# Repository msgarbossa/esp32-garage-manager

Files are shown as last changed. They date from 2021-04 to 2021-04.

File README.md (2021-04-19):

# ESP32 Garage Manager

## Basic features

- Remotely trigger a relay to open the garage door
- Magentic reed switch is used to determine whether the garage door is open or closed and send events when the state changes
- AHT10 temperature and humidity sensor sends regular updates (BME280 can be used instead using functions/temp-bme280.h instead of temp-ah10.h)
- Water leak sensor via a capacitive touch pin, intended to monitor a hot water heater for leaks
- OLED display alternates between Temp/Humidity and basic information (IP, device name, WiFi connection state, WiFi signal strength, door state, leak state)
- MQTT is used to publish and subscribe messages
- Node-RED interface to MQTT to process data, export Prometheus metrics, and send alerts for leaks or door left open at night
- Home Assistant and phone app is used for dashboard button to trigger door

## Parts

- [ESP32 devkit - 30 pin, integrated antenna](https://www.aliexpress.com/item/1005001267643044.html)
- [0.96" OLED - white, I2C](https://www.aliexpress.com/item/32896971385.html)
- [BME280 sensor](https://www.aliexpress.com/item/4001098967210.html) or [AHT10 sensor](https://www.aliexpress.com/item/4000125110813.html)
- [relay](https://www.aliexpress.com/item/32908761529.html)
- [magnetic reed switch](https://www.aliexpress.com/item/4001283716814.html)
- [passive piezo buzzer](https://www.aliexpress.com/item/4001317667682.html) or anything to make noise
- [alarm wire](https://www.amazon.com/gp/product/B01CT06M0A/) (500') - Used for magnetic reed switch connection, but useful for other connections.  It's 22 awg solid wire, which is easier to work with and solder than some of the cheap stranded wire.

## Diagram

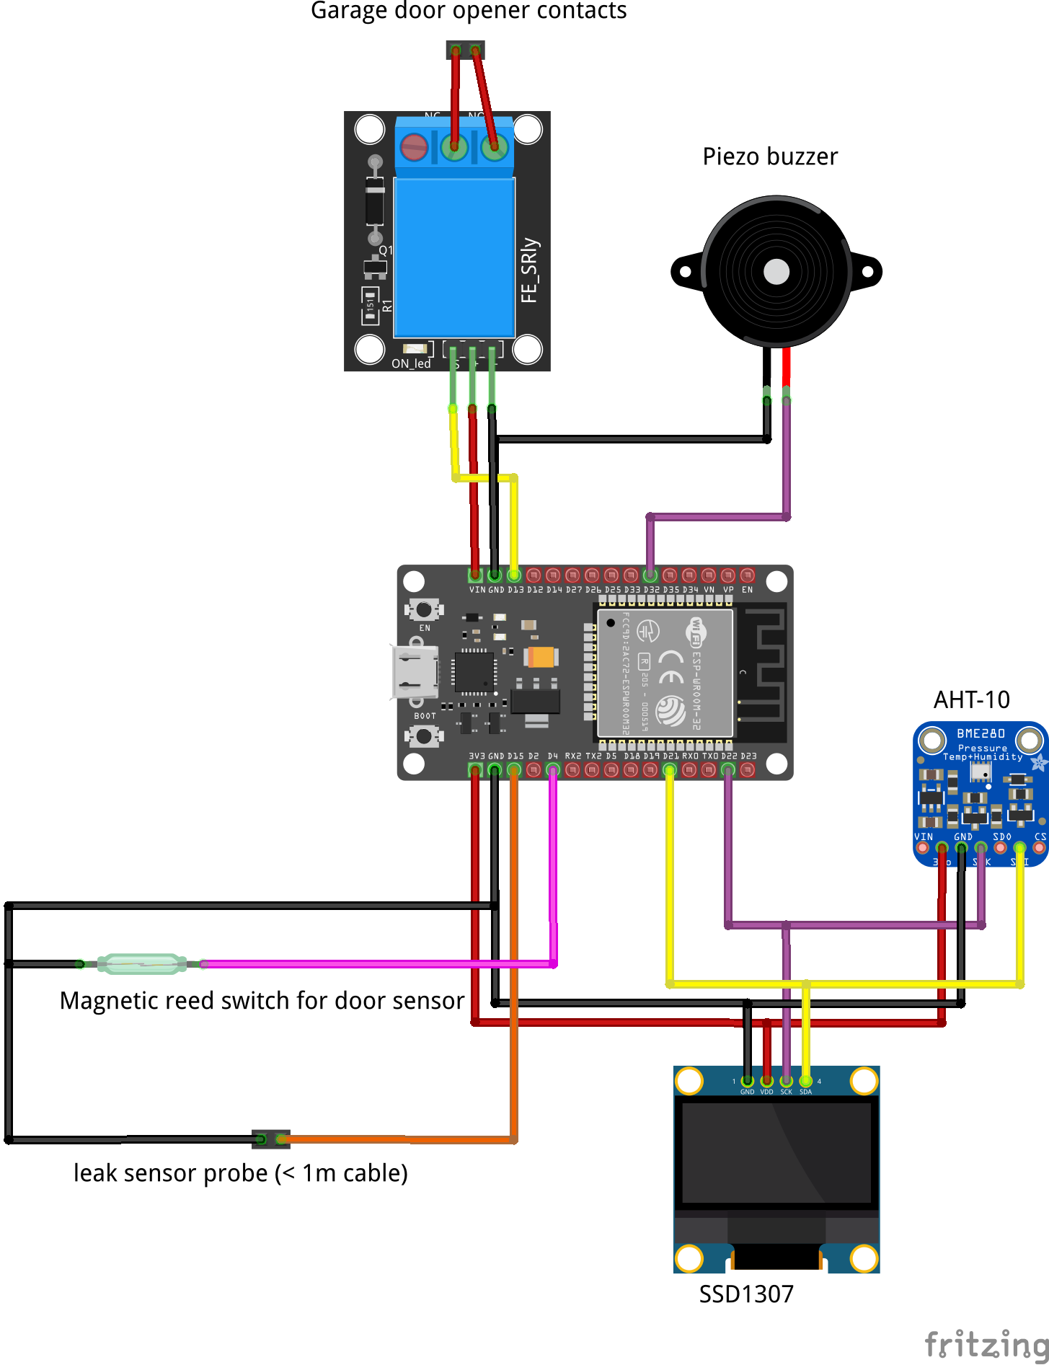
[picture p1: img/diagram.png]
diagram


## Assembly

I use these [inexepensive cases (10-pack)](https://www.amazon.com/gp/product/B07HKWNB93/), which are pretty easy for prototyping.  They can be cut with an X-acto knife and the X-acto knife can also "drill" holes with the tip. 

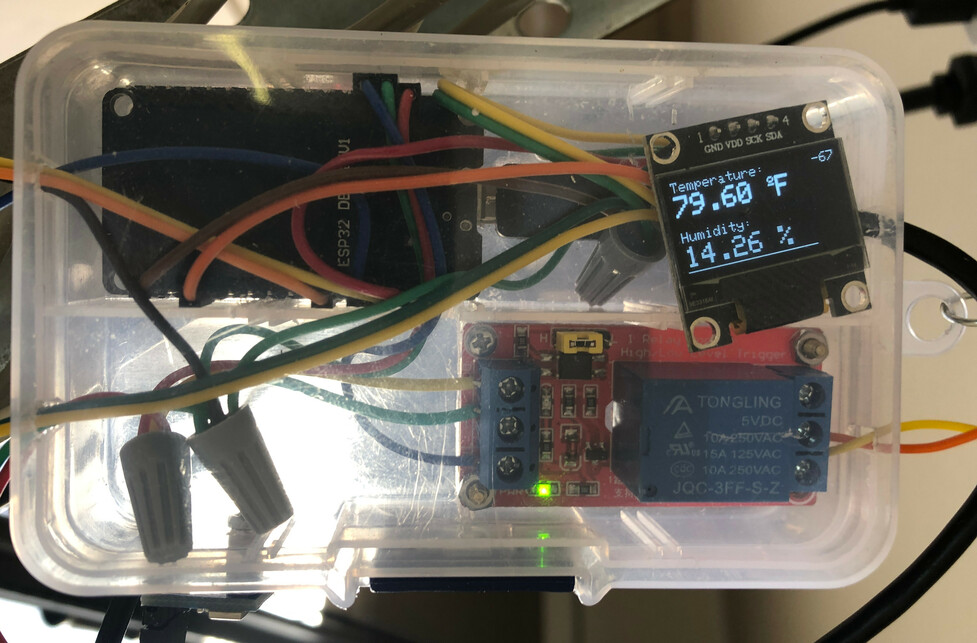
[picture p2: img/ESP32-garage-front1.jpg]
front1


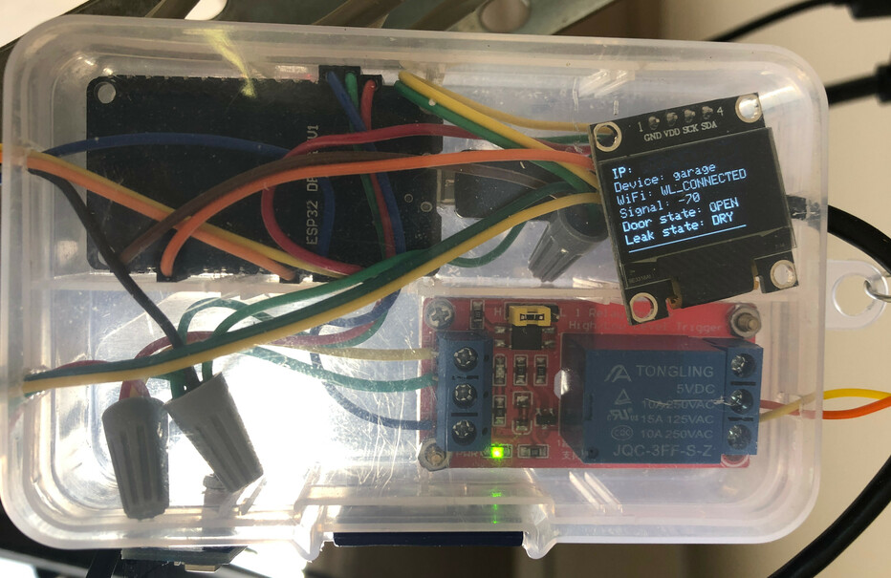
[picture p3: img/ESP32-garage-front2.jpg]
front2


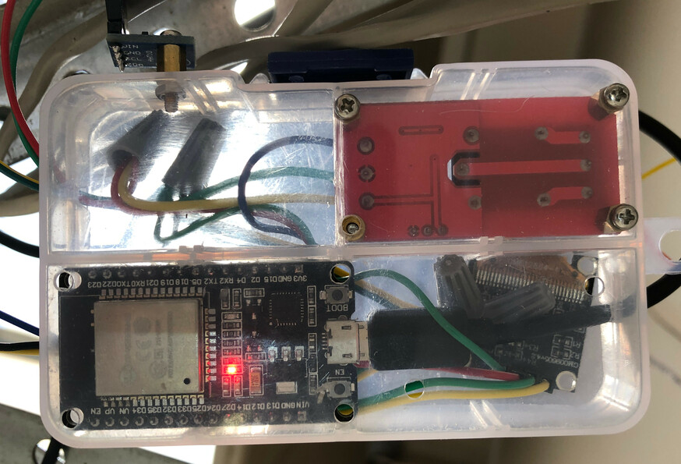
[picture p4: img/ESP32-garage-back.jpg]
back


The alarm wire can be used to run longer connections to the magnetic door sensor switch and the contacts for triggering the garage door.  If using the leak sensor, the ESP32 will need to be located near the leak sensor (\< 1 meter).  Dental-floss cases worked well due to the clamshell design and soft plastic.

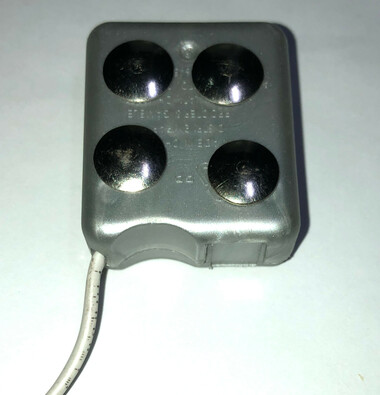
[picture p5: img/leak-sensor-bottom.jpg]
leak-sensor-bottom
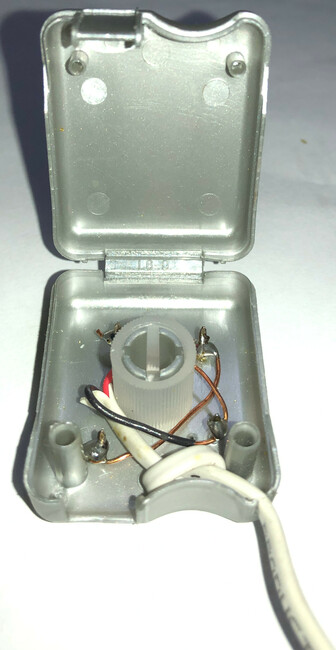
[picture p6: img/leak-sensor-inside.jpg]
leak-sensor-inside
  

## Node-RED

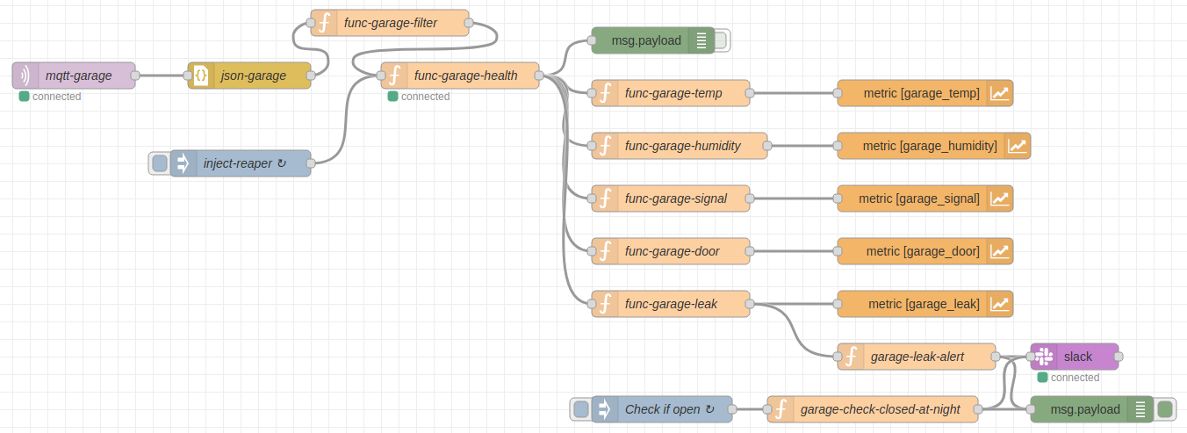
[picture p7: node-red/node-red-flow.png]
Node-RED flow

[JSON for above flow](node-red/flow.json)

The beginnig of the flow starts out very simple.  Node-RED listens on the MQTT topic for the sensor.  The messages get converted from JSON to payload objects.

To understand the rest of the flow, it's important to go over how the Prometheus node exporter works in Node-RED.  The orange metric boxes to the right-side of the flow generate the prometheus data shown below at \<node_red_url\>:1880/metrics.

```
# HELP garage_temp garage temp
# TYPE garage_temp gauge
garage1_temp 83.1

# HELP garage_humidity garage humidity
# TYPE garage_humidity gauge
garage_humidity 22.58

# HELP garage_signal garage signal
# TYPE garage_signal gauge
garage_signal -61

# HELP garage_door garage door
# TYPE garage_door gauge
garage_door 0

# HELP garage_leak garage leak
# TYPE garage_leak gauge
garage_leak 0
```

The challenge has been dealing with sensors that go offline.  The metric node would not receive an updated value and continue to display an old value.  This would show up in the graphs in Grafana as a flat-line.  There might be a more elegant solution, but what I've done for now is to use an inject node to regularly inject a healthcheck message into the flow.  The healthcheck function node uses node context to store the time of the last valid message that came from MQTT.  When the healthcheck message is injected, the time of the inject message is compared to the time of the last valid message.  If the time difference is greater than the threshold, the healthcheck node's status is set to "offline" and a new message is generated and passed along with the metric values set to zero.  The Grafana graphs are set to only display values greater than zero.

The functions to the left of each of the orange metric nodes simply reformat the payload messages to set the metric values as required for the Promtheus metric nodes.

The "Check if open" inject node is scheduled to check if the garage door is open at night.  There are 2 alert processing functions that send messages to Slack (door open and leak events).

Below is an example graph in Grafana.

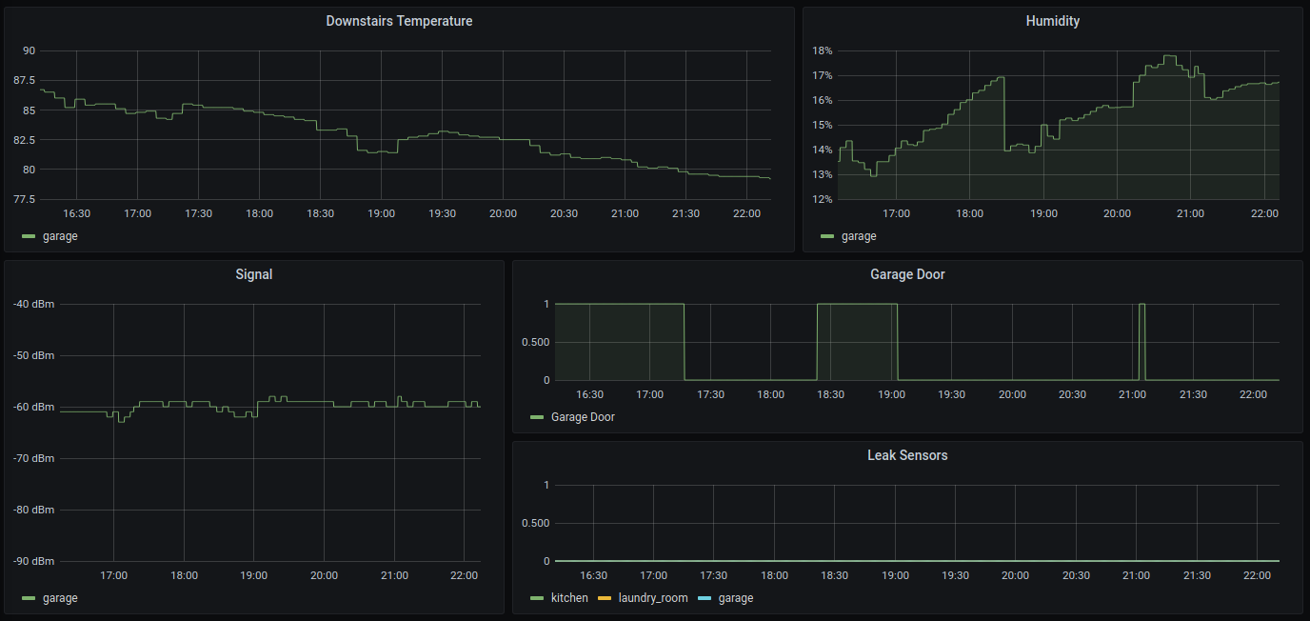
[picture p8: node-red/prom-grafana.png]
Prometheus - Grafana


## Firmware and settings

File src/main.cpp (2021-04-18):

#include <Arduino.h>
#include <WiFi.h>
extern "C" {
  #include "freertos/FreeRTOS.h"
  #include "freertos/timers.h"
}
#include <AsyncMqttClient.h>
#include <SPI.h>
#include <Wire.h>
#include <Adafruit_GFX.h>
#include <Adafruit_SSD1306.h>

#include "config/config.h"
#include "functions/ota.h"
#include "functions/attention.h"
#include "functions/temp-aht10.h"
#include "tasks/garage-door.h"
#include "tasks/leak-detect.h"

#ifdef __arm__
// should use uinstd.h to define sbrk but Due causes a conflict
extern "C" char* sbrk(int incr);
#else  // __ARM__
extern char *__brkval;
#endif  // __arm__

#define SCREEN_WIDTH 128 // OLED display width, in pixels
#define SCREEN_HEIGHT 64 // OLED display height, in pixels

// Declaration for an SSD1306 display connected to I2C (SDA, SCL pins)
#define OLED_RESET     -1 // Reset pin # (or -1 if sharing Arduino reset pin)
Adafruit_SSD1306 display(SCREEN_WIDTH, SCREEN_HEIGHT, &Wire, OLED_RESET);

// Variables to hold sensor readings
float temp;
float humidity;
// float pressure;
int doorStatus;
bool doorChanged;
int leakStatus;
bool leakChanged;

// Variables to hold sensor info
int8_t wifi_strength;
IPAddress ip;

unsigned short int displayCount = 2;

// Temperature MQTT Topics
#define MQTT_PUB_TEMP "home/" DEVICE_NAME "/metrics"
#define MQTT_SUB_CMD "home/" DEVICE_NAME "/cmd"

AsyncMqttClient mqttClient;
TimerHandle_t mqttReconnectTimer;
TimerHandle_t wifiReconnectTimer;
TimerHandle_t checkDoorTimer;
TimerHandle_t checkLeakTimer;

const long intervalMQTT   = 300000;    // Interval at which to publish sensor readings
unsigned long prevMillisMQTT = 0;   // Stores last time sensor was published
const long intervalSensor = 60000;    // Interval at which to read sensor and update display
unsigned long prevMillisSensor = 0;   // Stores last time sensor was published
unsigned long prevMillisDisplay = 0;   // Stores last time display was updated
const unsigned long intervalAlertMillis = 30000;  // How often to alert when leak sensor is wet
unsigned long prevMillisAlert = 0;
unsigned int countdownPerc;


const char* wl_status_to_string(int status) {
  switch (status) {
    case WL_NO_SHIELD: return "WL_NO_SHIELD";
    case WL_IDLE_STATUS: return "WL_IDLE_STATUS";
    case WL_NO_SSID_AVAIL: return "WL_NO_SSID_AVAIL";
    case WL_SCAN_COMPLETED: return "WL_SCAN_COMPLETED";
    case WL_CONNECTED: return "WL_CONNECTED";
    case WL_CONNECT_FAILED: return "WL_CONNECT_FAILED";
    case WL_CONNECTION_LOST: return "WL_CONNECTION_LOST";
    case WL_DISCONNECTED: return "WL_DISCONNECTED";
    default: return "UNKNOWN";
  }
}

void connectToWifi() {
  btStop(); // turn off bluetooth
  Serial.println("Connecting to Wi-Fi...");
  WiFi.begin(WIFI_NETWORK, WIFI_PASSWORD);
}

void connectToMqtt() {
  Serial.println("Connecting to MQTT...");
  mqttClient.connect();
}

void WiFiEvent(WiFiEvent_t event) {
  Serial.printf("[WiFi-event] event: %d\n", event);
  switch(event) {
    case SYSTEM_EVENT_STA_GOT_IP:
      Serial.println("WiFi connected");
      Serial.println("IP address: ");
      ip = WiFi.localIP();
      Serial.println(WiFi.localIP());
      connectToMqtt();
      break;
    case SYSTEM_EVENT_STA_DISCONNECTED:
      Serial.println("WiFi lost connection");
      xTimerStop(mqttReconnectTimer, 0); // ensure we don't reconnect to MQTT while reconnecting to Wi-Fi
      xTimerStart(wifiReconnectTimer, 0);
      break;
    default:
      break;
  }
}

void updateWiFiSignalStrength() {
  if(WiFi.isConnected()) {
    //serial_println(F("[WIFI] Updating signal strength..."));
    wifi_strength = WiFi.RSSI();
    // Serial.print("[WIFI] signal strength: ");
    // Serial.println(wifi_strength);
  }
}

void onMqttConnect(bool sessionPresent) {
  Serial.println("Connected to MQTT.");
  Serial.print("Session present: ");
  Serial.println(sessionPresent);
  uint16_t packetIdSub = mqttClient.subscribe(MQTT_SUB_CMD, 2);
  Serial.print("Subscribing at QoS 2, packetId: ");
  Serial.println(packetIdSub);
}

void onMqttDisconnect(AsyncMqttClientDisconnectReason reason) {
  Serial.println("Disconnected from MQTT.");
  if (WiFi.isConnected()) {
    xTimerStart(mqttReconnectTimer, 0);
  }
}

void onMqttPublish(uint16_t packetId) {
  Serial.print("Publish acknowledged.");
  Serial.print("  packetId: ");
  Serial.println(packetId);
}

void drawMeasurementProgress(int perc) {
  const byte Y = SCREEN_HEIGHT - 2;
  // display.drawRect(x, y, width, height, color)
  display.drawRect(0, Y, int(SCREEN_WIDTH * (perc/100.0)), 1, WHITE);
}

void displayStats() {
  // clear display
  display.clearDisplay();
  
  // display temperature
  display.setTextSize(1);
  display.setCursor(0,0);
  display.print("Temperature: ");
  display.setTextSize(2);
  display.setCursor(0,10);
  display.print(temp);
  display.print(" ");
  display.setTextSize(1);
  display.cp437(true);
  display.write(167);
  display.setTextSize(2);
  display.print("F");
  
  // display humidity
  display.setTextSize(1);
  display.setCursor(0, 35);
  display.print("Humidity: ");
  display.setTextSize(2);
  display.setCursor(0, 45);
  display.print(humidity);
  display.print(" %");

  // display wifi signal strength
  display.setTextSize(1);
  display.setCursor(110, 0);
  display.print(String(wifi_strength));

  drawMeasurementProgress(countdownPerc);
  
  display.display();
  //delay(1000); // Pause for 1 second
  vTaskDelay(1000 / portTICK_PERIOD_MS);
}

void displayInfo() {

  String currentState = wl_status_to_string(WiFi.status());

  // clear display
  display.clearDisplay();
  
  // display temperature
  display.setTextSize(1);
  display.setCursor(0,0);
  display.print("IP: ");
  display.print(ip);
  display.setCursor(0,10);
  display.print("Device: ");
  display.print(DEVICE_NAME);
  display.setCursor(0,20);
  display.print("WiFi: ");
  display.print(currentState);
  display.setCursor(0,30);
  display.print("Signal: ");
  display.print(String(wifi_strength));
  display.setCursor(0,40);
  display.print("Door state: ");
  if (doorStatus == 0) {
   display.print("CLOSED"); 
  } else {
    display.print("OPEN"); 
  }
  display.setCursor(0,50);
  display.print("Leak state: ");
  if (leakStatus == 0) {
   display.print("DRY"); 
  } else {
    display.print("WET"); 
  }

  drawMeasurementProgress(countdownPerc);

  display.display();
  vTaskDelay(1000 / portTICK_PERIOD_MS);
}

void sendMqttUpdate() {
  char msg[58];  // variable for MQTT payload
  sprintf(msg, "{\"t\":\"%0.2f\",\"h\":\"%0.2f\",\"s\":\"%d\",\"d\":\"%d\",\"w\":\"%d\"}", temp, humidity, wifi_strength, doorStatus, leakStatus);
  // uint16_t packetIdPub1 = mqttClient.publish(MQTT_PUB_TEMP, 1, true, msg);
  uint16_t packetIdPub1 = mqttClient.publish(MQTT_PUB_TEMP, 0, false, msg);
  Serial.printf("[MQTT] Publishing on topic %s at QoS 1, packetId: %i\n", MQTT_PUB_TEMP, packetIdPub1);
  Serial.println(msg);
}

void onMqttSubscribe(uint16_t packetId, uint8_t qos) {
  Serial.println("Subscribe acknowledged.");
  Serial.print("  packetId: ");
  Serial.println(packetId);
  Serial.print("  qos: ");
  Serial.println(qos);
}
void onMqttUnsubscribe(uint16_t packetId) {
  Serial.println("Unsubscribe acknowledged.");
  Serial.print("  packetId: ");
  Serial.println(packetId);
}

void onMqttMessage(char* topic, char* payload, AsyncMqttClientMessageProperties properties, size_t len, size_t index, size_t total) {
  Serial.println("Publish received.");
  Serial.print("  topic: ");
  Serial.println(topic);
  Serial.print("  qos: ");
  Serial.println(properties.qos);
  Serial.print("  dup: ");
  Serial.println(properties.dup);
  Serial.print("  retain: ");
  Serial.println(properties.retain);
  Serial.print("  len: ");
  Serial.println(len);
  Serial.print("  index: ");
  Serial.println(index);
  Serial.print("  total: ");
  Serial.println(total);

  char s_payload[len + 1];
  String payload2 = "";
  if (len < 20) {
    Serial.print("  payload: ");
    s_payload[len] = '\0';
    strncpy(s_payload, payload, len);
    Serial.println(s_payload);
    payload2 = s_payload;
  } else {
    Serial.println(" payload len>20");
  }
  if (payload2 == "blink") {
    blink_now();
    prevMillisMQTT = 0;
  }
  if (payload2 == "toggle") {
    play_sound();
    toggleGarageRelay();
  }

}

void setup() {
  Serial.begin(115200);
  Serial.println();
  pinMode (LED_PIN, OUTPUT);

  Wire.begin(I2C_SDA, I2C_SCL);

  // SSD1306_SWITCHCAPVCC = generate display voltage from 3.3V internally
  if(!display.begin(SSD1306_SWITCHCAPVCC, 0x3C)) { 
    Serial.println(F("SSD1306 allocation failed"));
    for(;;); // Don't proceed, loop forever
  }
  display.clearDisplay();
  display.setTextColor(WHITE);

  // Set up temp sensor
  setupTemp();

  // Set up garage dooor monitor and leak monitor
  monitorDoorSetup();
  leakSetup();
  
  mqttReconnectTimer = xTimerCreate("mqttTimer", pdMS_TO_TICKS(2000), pdFALSE, (void*)0, reinterpret_cast<TimerCallbackFunction_t>(connectToMqtt));
  wifiReconnectTimer = xTimerCreate("wifiTimer", pdMS_TO_TICKS(2000), pdFALSE, (void*)0, reinterpret_cast<TimerCallbackFunction_t>(connectToWifi));
  checkDoorTimer = xTimerCreate("doorTimer", pdMS_TO_TICKS(GARAGE_DOOR_MONITOR_MS), pdTRUE, (void*)0, reinterpret_cast<TimerCallbackFunction_t>(monitorDoorState));
  checkLeakTimer = xTimerCreate("leakTimer", pdMS_TO_TICKS(LEAK_MONITOR_MS), pdTRUE, (void*)0, reinterpret_cast<TimerCallbackFunction_t>(checkLeakStatus));

  WiFi.onEvent(WiFiEvent);

  mqttClient.onConnect(onMqttConnect);
  mqttClient.onDisconnect(onMqttDisconnect);
  mqttClient.onSubscribe(onMqttSubscribe);
  mqttClient.onUnsubscribe(onMqttUnsubscribe);
  mqttClient.onMessage(onMqttMessage);
  mqttClient.onPublish(onMqttPublish);
  mqttClient.setServer(MQTT_HOST, MQTT_PORT);
  mqttClient.setCredentials(MQTT_USER, MQTT_PASSWORD);
  connectToWifi();
  setupOTA();
  xTimerStart(checkDoorTimer, 0);
  xTimerStart(checkLeakTimer, 0);
}

void loop() {
  ArduinoOTA.handle();

  unsigned long currentMillis = millis();
  bool forceMqttUpdate = false;

  // read sensor every intervalSensor millis
  if (currentMillis - prevMillisSensor >= intervalSensor) {
    // Save the last time a new reading was published
    prevMillisSensor = currentMillis;
    measureTemp();
  }

  // update display every DISPLAY_INTERVAL and rotate display screens
  if (currentMillis - prevMillisDisplay >= DISPLAY_INTERVAL) {
    prevMillisDisplay = currentMillis;
    countdownPerc = 100-(((currentMillis-prevMillisMQTT)/double(intervalMQTT))*100);  // time until MQTT interval expires
    updateWiFiSignalStrength();
    if (displayCount == 2) {
      displayStats();
      displayCount = 1;
    } else {
      displayInfo();
      displayCount = 2;
    }
  }

  if ((doorChanged == true) || (leakChanged == true)) {
    forceMqttUpdate = true;
  }

  // If wet, do sound alert every intervalAlertMillis
  if (leakStatus == 1) {
    if (currentMillis - prevMillisAlert >= intervalAlertMillis) {
      prevMillisAlert = millis();
      blink_now();
    }
  }

  // publish a new MQTT message everyintervalMQTT millis
  if ((currentMillis - prevMillisMQTT >= intervalMQTT) || (forceMqttUpdate == true)) {
    // Save the last time a new reading was published
    prevMillisMQTT = currentMillis;
    doorChanged = false;
    leakChanged = false;
    blink_now();
    sendMqttUpdate();
  }
}

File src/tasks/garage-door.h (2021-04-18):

// #define CLOSED LOW	
// #define OPEN HIGH

#include <Arduino.h>
#include "../config/config.h"

extern bool doorChanged;
extern int doorStatus;

short int getDoorStatus() {
    // digitalRead returns 1/HIGH/OPEN or 0/LOW/CLOSED
    // LOW = magnetic switch connected = door closed
    // HIGH = magentic switch broken = door open
    short int status = digitalRead(GARAGE_MAG_SWITCH_PIN);
    return status;
}

void monitorDoorSetup() {
    // pinMode(GARAGE_RELAY_PIN, INPUT_PULLUP);  // for the odd relay triggered by grounding the input pin
    pinMode(GARAGE_RELAY_PIN, OUTPUT);  // for stardard relay (triggered w/ 3.3V)
    pinMode(GARAGE_MAG_SWITCH_PIN, INPUT_PULLUP);
    doorStatus = getDoorStatus();
}

void toggleGarageRelay() {
    Serial.println("Garage relay toggle");
    // pinMode(GARAGE_RELAY_PIN, OUTPUT);  // for the odd relay triggered by grounding the input pin
    digitalWrite(GARAGE_RELAY_PIN, HIGH); // turn on the relay (standard relay triggered w/ 3.3V)
    vTaskDelay(300 / portTICK_PERIOD_MS);
    // pinMode(GARAGE_RELAY_PIN, INPUT_PULLUP);  // for the odd relay triggered by grounding the input pin
    digitalWrite(GARAGE_RELAY_PIN, LOW);  // turn off the relay (standard relay triggered w/ 3.3V)
}

void monitorDoorState() {
    short int newDoorStatus = getDoorStatus();
    if (newDoorStatus != doorStatus) {
        doorStatus = newDoorStatus;
        doorChanged = true;
        Serial.print("[GARAGE] Door has changed to: ");
        if (doorStatus == LOW) {
            Serial.println("CLOSED");
        } else {
            Serial.println("OPEN");
        }
    }
}
